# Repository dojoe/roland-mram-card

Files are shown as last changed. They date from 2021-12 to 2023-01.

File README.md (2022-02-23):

# Roland compatible multi-bank MRAM memory card

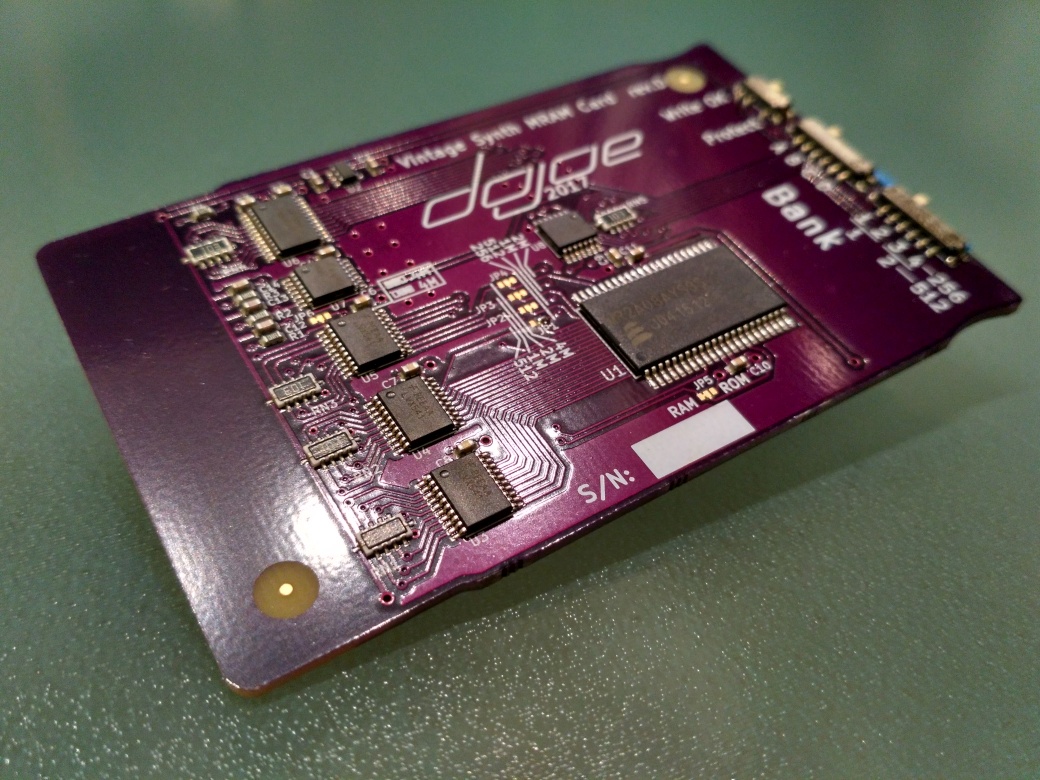
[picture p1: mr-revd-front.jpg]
[](mr-revd-front.jpg) (click to enlarge)

This is a replacement memory card for old Roland instruments of the late 80s and early 90s, such as the D-50 synthesizers, the JV-1080 and JV-2080 rack synths or the JD-880. It is meant to replace memory cards of the M-128, M-256 and M-512 lines (including M-256E, M-512G and all other suffixes). Some Akai devices from the same age actually use a compatible card format (BR-16 and BR-32) and this card will work in those too.

It doesn't need any kind of backup battery since it uses non-volatile MRAM for data storage, and thanks to the large memory chip used it emulates multiple virtual cards ("banks") which are selectable via slide switches - one of these memory cards will emulate 8x M-512 or 16x M-256 depending on the setting of a solder jumper.

The card has been developed with a lot of testing help from the community over at [the VintageSynth forums](https://forum.vintagesynth.com/viewtopic.php?f=24&t=76886) and over 900 units have been manufactured and sold since then - with near zero complaints :) Since the beginning of the project, we had plans to eventually publish the design data and source code for the card so it would stay available to everyone once we stopped making and selling them. So here it is!

## Compatibility

* **Tested and fully compatible:** Roland A-90, D-5, D-20, D-50, D-550, D-10, D-110, D-70, U-20, JD-800, JD-990, JV-880, JV-1000, JV-1080, JV-2080, R-880 (GC-8), R-8M, GR-1, GR-50, PM-16, TR-626, Akai MX-1000, VX600.
* **Mostly compatible:** Roland TD-10, TD-20. The card reportedly has errors when inserted all the way, but pulled back 1/8th of an inch it works fine.
* **Not compatible:** Roland VG-8, Peavey Tubefex.
* Some units like the Roland U-110 and U-220 only accept ROM cards, not RAM cards. Naturally, this RAM card replacement does not work in those, either.

## Differences to the cards we sell

Functionally, this design is 100% identical to the cards we sell online. I did make some changes to the appearance however to make homemade cards clearly distinguishable from ours.

Also, one part we use (a Bourns CAT25 SMD resistor network) is no longer being manufactured, so I updated the BOM with a Panasonic part as a drop-in replacement.

## Directories

* [mram-card](mram-card): The memory card hardware design files.
* [datasheets](datasheets): Data sheets for most of the parts used.
* [testbench](testbench): The testbench I'm using to test every card before they go out to customers.

## Making cards

Send the [KiCAD PCB file](mram-card/d50mram.kicad_pcb) or the [Gerbers](mram-card/gerbers.zip) to your favorite board house - or order directly from OSHPark:



As for parts, check out the [bill of materials](mram-card/d50mram.bom.csv).

Did you build one, or even more than one? We'd love to hear from you, feel free to leave a comment in the [card builder thread](https://github.com/dojoe/roland-mram-card/issues/2) :)

# Licenses

## Memory card

<br /><span xmlns:dct="http://purl.org/dc/terms/" property="dct:title">The hardware design of the <a href="https://github.com/dojoe/roland-mram-card">Roland compatible multi-bank MRAM memory card</a></span> by <a xmlns:cc="http://creativecommons.org/ns#" href="https://github.com/dojoe" property="cc:attributionName" rel="cc:attributionURL">Joachim "dojoe" Fenkes</a> is licensed under a <a rel="license" href="http://creativecommons.org/licenses/by-sa/4.0/">Creative Commons Attribution-ShareAlike 4.0 International License</a>.

## Testbench

Please see the [testbench README](testbench/README.md) for testbench license information.

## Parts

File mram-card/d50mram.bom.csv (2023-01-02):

Source: | D:\Projects\d50_mram_card\opensource\mram-card\d50mram.kicad_sch
Date: | 2023-01-02 14:01:17
Tool: | Eeschema (6.0.7)
Generator: | C:\Program Files\KiCad\6.0\bin\scripting\plugins/bom_csv_grouped_by_value.py
Component Count: | 42
Individual Components:
Item | Qty | Reference(s) | Value | LibPart | Footprint | Datasheet | Digikey | Mouser
 |  | C1 | 1uF X7R | d50mram:C
 |  | C2 | 1uF X7R | d50mram:C
 |  | C3 | 100n | d50mram:C
 |  | C4 | 100n | d50mram:C
 |  | C5 | 100n | d50mram:C
 |  | C6 | 100n | d50mram:C
 |  | C7 | 100n | d50mram:C
 |  | C8 | 100n | d50mram:C
 |  | C9 | 100n | d50mram:C
 |  | C10 | 100n | d50mram:C
 |  | C11 | 100n | d50mram:C
 |  | C12 | 100p | d50mram:C
 |  | C13 | 100p | d50mram:C
 |  | C14 | 100p | d50mram:C
 |  | J1 | D50-EDGECONN | d50mram:D50-EDGECONN
 |  | JP1 | JUMPER3 | d50mram:JUMPER3
 |  | JP2 | JUMPER3 | d50mram:JUMPER3
 |  | JP3 | JUMPER3 | d50mram:JUMPER3
 |  | JP4 | JUMPER3 | d50mram:JUMPER3
 |  | JP5 | JUMPER3 | d50mram:JUMPER3
 |  | JP6 | JUMPER3 | d50mram:JUMPER3
 |  | R1 | 100R | d50mram:R
 |  | R2 | 100R | d50mram:R
 |  | R3 | 100R | d50mram:R
 |  | R4 | 100R | d50mram:R
 |  | RN1 | 10k | d50mram:CAT25 |  |  | U8103CT-ND | 667-EXB-E10C103J
 |  | RN2 | 10k | d50mram:CAT25 |  |  | U8103CT-ND | 667-EXB-E10C103J
 |  | RN3 | 10k | d50mram:CAT25 |  |  | U8103CT-ND | 667-EXB-E10C103J
 |  | RN4 | 10k | d50mram:CAT25 |  |  | U8103CT-ND | 667-EXB-E10C103J
 |  | RN5 | 10k | d50mram:CAT25 |  |  | U8103CT-ND | 667-EXB-E10C103J
 |  | SW1 | SPDT | d50mram:SPDT |  |  | 563-1102-1-ND | 229-CUS-12TB
 |  | SW2 | SP4T | d50mram:SP4T |  |  | 563-1104-1-ND | 229-CUS-14TB
 |  | SW3 | SP4T | d50mram:SP4T |  |  | 563-1104-1-ND | 229-CUS-14TB
 |  | TP1 | CONN_6 | d50mram:CONN_6
 |  | U1 | EST-MR2A08A | d50mram:EST-MR2A08A |  |  | 819-1004-ND | 936-MR2A08AYS35
 |  | U2 | MIC5265-3.3YD5 | d50mram:TC1054 |  |  | 576-2835-1-ND | 998-MIC5265-3.3YD5TR
 |  | U3 | 74LVX541 | d50mram:74LS541 |  |  | 74LVX541MTCXCT-ND | 512-74LVX541MTCX
 |  | U4 | 74LVX541 | d50mram:74LS541 |  |  | 74LVX541MTCXCT-ND | 512-74LVX541MTCX
 |  | U5 | 74LVX541 | d50mram:74LS541 |  |  | 74LVX541MTCXCT-ND | 512-74LVX541MTCX
 |  | U6 | 74LVX4245 | d50mram:74x4245 |  |  | 74LVX4245MTCXCT-ND | 512-74LVX4245MTCX
 |  | U7 | 74HC02 | d50mram:74LS02P |  |  | MM74HC02MTCXCT-ND | 512-MM74HC02MTCX
 |  | U8 | 74HC02 | d50mram:74LS02P |  |  | MM74HC02MTCXCT-ND | 512-MM74HC02MTCX
Collated Components:
Item | Qty | Reference(s) | Value | LibPart | Footprint | Datasheet | Digikey | Mouser
1 | 2 | C1, C2 | 1uF X7R | d50mram:C
2 | 9 | C3, C4, C5, C6, C7, C8, C9, C10, C11 | 100n | d50mram:C
3 | 3 | C12, C13, C14 | 100p | d50mram:C
4 | 1 | J1 | D50-EDGECONN | d50mram:D50-EDGECONN
5 | 6 | JP1, JP2, JP3, JP4, JP5, JP6 | JUMPER3 | d50mram:JUMPER3
6 | 4 | R1, R2, R3, R4 | 100R | d50mram:R
7 | 5 | RN1, RN2, RN3, RN4, RN5 | 10k | d50mram:CAT25 |  |  | U8103CT-ND | 667-EXB-E10C103J
8 | 1 | SW1 | SPDT | d50mram:SPDT |  |  | 563-1102-1-ND | 229-CUS-12TB
9 | 2 | SW2, SW3 | SP4T | d50mram:SP4T |  |  | 563-1104-1-ND | 229-CUS-14TB
10 | 1 | TP1 | CONN_6 | d50mram:CONN_6
11 | 1 | U1 | EST-MR2A08A | d50mram:EST-MR2A08A |  |  | 819-1004-ND | 936-MR2A08AYS35
12 | 1 | U2 | MIC5265-3.3YD5 | d50mram:TC1054 |  |  | 576-2835-1-ND | 998-MIC5265-3.3YD5TR
13 | 3 | U3, U4, U5 | 74LVX541 | d50mram:74LS541 |  |  | 74LVX541MTCXCT-ND | 512-74LVX541MTCX
14 | 1 | U6 | 74LVX4245 | d50mram:74x4245 |  |  | 74LVX4245MTCXCT-ND | 512-74LVX4245MTCX
15 | 2 | U7, U8 | 74HC02 | d50mram:74LS02P |  |  | MM74HC02MTCXCT-ND | 512-MM74HC02MTCX

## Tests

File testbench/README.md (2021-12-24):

# Roland Memory Card Testbench

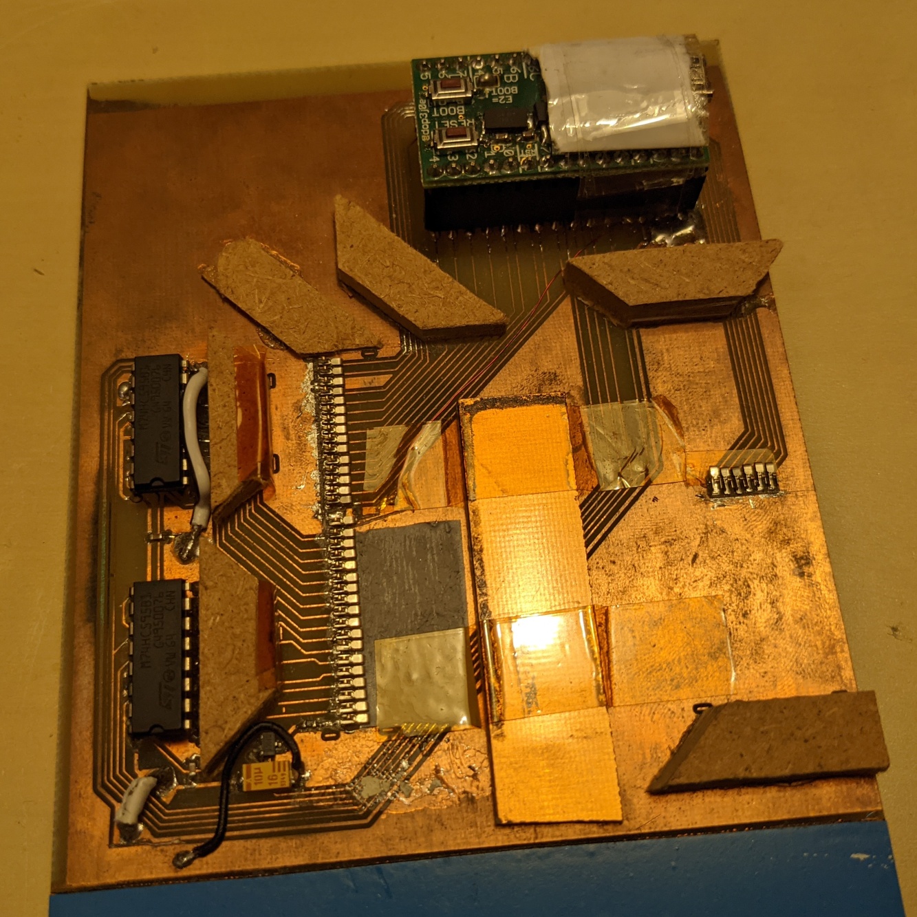
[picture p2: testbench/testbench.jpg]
[](testbench.jpg) (click to enlarge)

This is a quick and dirty test jig I built to test the memory card. It performs these tests, in order:

1. Check voltage rails (5V provided from outside, 3.3V generated on the card).
2. Single bank full read/write with data checking to test address and data lines.
3. Test write protect and bank switches - the user is prompted to operate the switches while the test program monitors the switch positions.
4. Verify bank switching logic - while the bank switches are tested, the test program writes a byte value identifying the bank to each and checks in a second pass that all values are read back correctly.

In addition to that it also has a couple debugging features: It can write and read memory cards (one bank at a time) and dump the current value of all microcontroller IO ports to the serial console (to test the test jig itself).

# Hardware

The test jig is built around my ATMega32U4 mini breakout board, the TinyMega - any 32U4 based Arduino board should do the trick though. I updated the schematics to reflect a more generic ATMega32U4 and added the user LED and user button that are connected to pins E6 and E2 on my board respectively.

**The PCB layout is only for illustrative purposes and not recommended for use!** It no longer matches the schematics, does not reflect some board modifications I have made in the meantime, and generally is a quick single-sided abomination I whacked together to get a test jig made over the weekend :) You can copy the arrangement of the spring contacts but should really redesign the rest from scratch.

Speaking of which, the spring contacts I've used are ["Micro Universal Contact Z 2.5mm"](../datasheets/springcontact.pdf) by ITT Cannon, Digikey P/N 120220-0312.

As you can see when looking at the schematics, the test jig uses every single I/O pin of the microcontroller. Address bits A0..A15 are generated via a chain of 74HC595 shift registers, all other signals are operated and monitored directly. Pin E6 ends up doing double duty - usually it just drives the LED to indicate test progress but a special 1Mbit write/dump mode was added later on that uses this pin for an additional address line.

A P-MOSFET is used to turn power to the card under test on and off; the small series resistor R2 limits the current in case of a short or near-short on the card. It will also cause a significant voltage drop in case the card isn't shorted but draws more current than expected - this will be detected in step 1 above and will fail the test.

The memory card has six test points that are used to read back the position of the four-way slide switches. The test program will poll these (with some debouncing logic) to pace the progress of steps 3+4 above in lockstep with the user moving the switches.

# Software

The test program is as quick and dirty a hack as is the hardware - it is based on the VirtualSerial demo program from the LUFA USB library, with almost no modifications to the USB serial code. All the test code is contained within [test.c](firmware/test.c), which is the only file _not_ shamelessly yoinked from LUFA.

The test program has four modes:

* Test mode, which will execute the test sequence.
* Dump mode, which will dump the entire card content to the serial console as a binary stream.
* Program mode, which will write binary data coming in via the serial console to the card.
* DIO monitor mode, which will keep printing the state of the I/O ports to the serial console.

For Test, Dump and Program mode, you can additionally select a card size; Test mode supports 256 and 512 kbit, Dump and Program modes additionally support 128 and 1024 kbit cards. The default upon startup is Test mode for 256 kbit cards.

You can switch modes by sending characters over the serial link: t, p, d, m select Test, Program, Dump and Monitor mode respectively, and 1..4 select 128, 256, 512 and 1024 kbit sizes.

To connect to the test jig, use a simple terminal program like [RealTerm](https://realterm.sourceforge.io/).

Regardless of mode, pushing the user button starts an operation.

## Test mode

Once you push the button, the test program will run through the tests in this order:

1. Turn off the user LED (in case it was turned on)
2. Test voltage rails
3. Check that all slide switches are in the right position (write protect off, bank A1 selected)
4. Read/write test of bank A1
5. Detect card size, fail if detected size doesn't match what's configured via serial
6. Turn on the user LED to indicate progress to the user
7. Test write protect switch: User must turn write protect on, then off again
8. Turn the user LED back off
9. Test ABCD bank switch: User must move switch through all positions from A thru D and then back again
10. Test 1234 bank switch in the same way
11. If we get here without error, the test passes - turn on the user LED to indicate success

If any of these steps fails, the test will abort and the user LED will blink. Also, whenever the program is waiting for user action, the user can instead push the button to abort the test.

## Dump mode

Once you push the button, the test program will read the entire card and output the contents to the serial link as a stream of bytes. The idea is that you configure dump mode and the correct size via your terminal program, then start a capture to file in the terminal program and push the button.

## Program mode

This is similar to Dump mode, except that your terminal program will be the one sending bytes to the test jig. As you push the button, the test program will print a message prompting you to send data, then you can have your terminal program send a binary file directly to the serial line. The test program will expect exactly as many bytes as you set up earlier.

# Licenses

 <p xmlns:cc="http://creativecommons.org/ns#" xmlns:dct="http://purl.org/dc/terms/">The hardware (schematics, example layout) of <a property="dct:title" rel="cc:attributionURL" href="https://github.com/dojoe/roland-mram-card/tree/master/testbench">Roland Memory Card Testbench</a> by <a rel="cc:attributionURL dct:creator" property="cc:attributionName" href="https://github.com/dojoe">Joachim "dojoe" Fenkes</a> is marked with <a href="http://creativecommons.org/publicdomain/zero/1.0?ref=chooser-v1" target="_blank" rel="license noopener noreferrer" style="display:inline-block;">CC0 1.0</a></p>

The actual test code, [test.c](firmware/test.c), is licensed under [the Unlicense](https://unlicense.org).

All other code in the firmware directory is copied or adapted from [LUFA](http://www.fourwalledcubicle.com/LUFA.php) and covered by [LUFA's license](firmware/LUFA/License.txt).

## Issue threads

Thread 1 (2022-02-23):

Equivalent Drop-In SMD Resistor Network

MrMojoRisinGottaKeepOnRisin, 2022-02-23:
I just built and tested three DOJOE Roland MRAM Cards using the new part from Panasonic (P/N: **EXB-E10C103J**) and all is well. The equivalent SMD Resistor Network you have listed in the BOM is indeed a valid drop-in replacement for the Bourns CAT25. Same footprint, specs and everything.

dojoe, 2022-02-23:
Thanks a lot for reporting back! I updated the README.

Closed 2022-02-23.

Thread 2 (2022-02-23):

Card builder thread!

dojoe, 2022-02-23:
Built your own card(s)? Leave a comment in here so we know how far our design is spreading :) We'd be interested in your rough location too (out of pure curiosity) but we'll also be happy if you just say hi!

MrMojoRisinGottaKeepOnRisin, 2022-02-23:
I'm on the East Coast, U.S.A. I purchased a pre-built Roland Multi-Bank MRAM Card back in 2021. One of the coolest new gadgets I own! I'm very grateful to the designer for the newly released BOM, schematics and plans. I commend DOJOE for supplying all of this free info and for supporting the DIY community. Very generous, indeed!! I have built three of these new cards from scratch so far and they all work great. Assembly was easy and the components are spaced out on the PCB with minimal crowding. I was able to solder all components by hand and did not use solder paste or a solder plate. Lots of flux. I used OSHPark to fabricate the PCB's and have always had outstanding luck with that company over the years. Quick turnaround and **Free Shipping** to anywhere in the world!

maddmannmatt, 2022-03-21:
Forgive my confusion on this matter, but does OSHPark build the whole card for you or do they just provide the PCBs?

MrMojoRisinGottaKeepOnRisin, 2022-03-21:
_> Forgive my confusion on this matter, but does OSHPark build the whole card for you or do they just provide the PCBs?_

OSHPark only supplies the PCB's. You need to source all of the parts and solder all of the components yourself.

andyc2k, 2022-04-06:
Thanks for open-sourcing this! FYI, it looks like the Panasonic EXB-E10C103J resistor network is out of stock on both DigiKey & Mouser, but there are still some Bourns CAT25-103JALF available from RS.

Benito-H, 2022-07-13:
I'm from Vancouver BC, and will be building one of these for my D-110. I have all the data sheets, but have a question about the surface mount capacitors and resistors.  What rating should I get (operating voltage/power rating), as there is a wide range to choose from, and this info is not included in the data sheets?  I am a newbie at this so apologize for my ignorance.

MrMojoRisinGottaKeepOnRisin, 2022-07-14:
> The board (sent Gerbers to PCBWAY) with all components installed is an extremely tight to fit into the card slot. The main RAM chip actually has a line/mark down it from being inserted into the card slot. What thickness were the original production boards?

I measured my original production PCB and it is 1.5mm. The DIY PCB's I bought from OSHPark are 1.4mm. I don't get any lines/marks when using either on a U-20, D-110 or JV-880 and both versions are a good fit on these three synths when inserting/removing.

MrMojoRisinGottaKeepOnRisin, 2022-07-14:
> I have all the data sheets, but have a question about the surface mount capacitors and resistors. What rating should I get (operating voltage/power rating)?

For my DIY synth projects using SMD components, when choosing resistors and capacitors without any specs shown in the BOM (just to play it safe) I always use Resistors 100V or greater @1/4W and Capacitors 35V or greater. Prior to the component shortage and price hikes of 2020, the extra cost for this high Voltage ceiling was minimal. Nowadays, urrrghhhhh!

These are the resistors and capacitors I used for my build:
100 Ohm - PANASONIC P/N: **ERJ-PA3F1000V**
10K Array - PANASONIC P/N: **EXB-E10C103J**
100pF - MURATA P/N: **GCM1885C2A101FA16D**
100nF - TDK P/N: **C1608X7S2A104K080AB**
1uF - TDK P/N: **CGA3E1X7R1V105K080AE**

Benito-H, 2022-07-16:
Hi MrMojo,

Great. thank you for your help. I am ordering the components from mouser, but there is a back order on the MIC5265-3.3YD5 chip until October.  I'll have to be patient, I guess.  Grrrr!

andyc2k, 2022-07-18:
I've built a couple of cards here in Tokyo using PCBs from OSHPark. I'm planning to use this to make a permanent backup of the Akai VX600 factory presets and ideally dump the data to a file. Next step will be to build the test jig - has anyone else tried this yet?

dojoe, 2022-07-18:
> The board (sent Gerbers to PCBWAY) with all components installed is an extremely tight to fit into the card slot. The main RAM chip actually has a line/mark down it from being inserted into the card slot. What thickness were the original production boards?

@MartyMidi The original boards were 1.6mm plus parts. Some devices' slots have a habit to warp and become tighter with age; that's when they scrape the main memory chip. This is known to happen in JD-1080s for example and isn't causing any kind of problem.

> What rating should I get (operating voltage/power rating), as there is a wide range to choose from, and this info is not included in the data sheets?

@Benito-H For caps, the board runs at 3.3V or 5V; I usually pick twice that for margin, so 10V should be plenty. As for stability rating, go with X7R; at the capacitances the board uses the X7Rs aren't more expensive than the lesser ratings these days.

For the resistors, use the ubiquitous 1/10W type, that's the cheap jellybean type for 0603 sizes and none of these will be seeing any significant current.

> Next step will be to build the test jig - has anyone else tried this yet?

@andyc2k Not that I'm aware of; you'll probably have to redesign most of the board (I take it you already saw the big fat warning in the README) and add the actual ATmega part plus support components instead of the devboard header I had on there. If you do I would be delighted about a PR :)

> I am ordering the components from mouser, but there is a back order on the MIC5265-3.3YD5 chip until October.

@Benito-H You may want to check out #5 :)

Benito-H, 2022-07-19:
@dojoe Thanks for the pointer to #5 I have ordered the alternate part, and all the other components.

tsanderakis, 2022-07-28:
Cant`t get my card running. It`s for a Roland D550 but it is allways telling me  "illegal card" Can`t find really good information on how formatting cards with my D550. Think this is a different procedure like the Keyboard D50 version. The solder on the card is on the right side for 256 at JP1. PCB is from JLCPCB and 1.6mm. I was thinking that 0.1mm more is not that much and in my opinion and feeling when pushing it in it fits well.
https://www.sweetwater.com/sweetcare/articles/roland-d-550-saving-ram-card/
Arrays are again avaiable at Mouser.

dojoe, 2022-07-28:
There must be an "initialize" option in some tools menu. That's what formatting is called on some Rolands. Illegal card usually just means it needs to be initialized. Remember that you have to initialize each bank separately. (Also remember to read the manual if you haven't already.)

If after initialization the card is still "illegal" there might be something bad about the hardware (like a badly connected address or data line).

tsanderakis, 2022-07-28:
The dokumentation of the D550 seems a little bit confusing. In the service manual, found one on the net, they are writing for testmode press and hold patch bank 2, patch bank 6, and edit and turn machine on. Looks like there is a translation error in the manual. If you use exit instead of edit its working.

Einschalten, während Sie die folgenden Tasten gedrückt halten:

1> PB2+PN6+edit=ROM-Versionsnummer identifizieren
2> PB2+PN6+exit=Testmodus aufrufen
3> PB2+PN6+enter=Initialisierung (Werkseinstellung wiederherstellen)
4> PB2+PN6+write=D/A-Anpassungsmodus aufrufen
found this on the net.

In test mode the card shows no read no write so no wonder not initialized but finds something. So what I try tomorrow is building a second card.  I have 2xD550 and on both same problems. Found in the original owners manual just only somewhere press 2x enter when it is not possible to write to the card. ???
Soldering? Not a total beginner. Did some STMs in the last few years and 0603.
Nothing like for D50 keyboard version.
Data Transfer, Int->Crd, Split-Point press and hold, press Enter

sorry, rough location is Upper Neanderthal

tsanderakis, 2022-07-29:
Ready with No. 2. This one is working so everything fine. For initializing you have just to press Data Transfer,  with cursor button go to int->card, press enter button, when you see illegal Card push enter again and then once more enter. This is for D550 not for D50. So now I have to find out whats wrong with No. 1.
@dojoe  Thanks for your help

andyc2k, 2022-08-21:
Hi. I was able to build the test jig and dump the binary data from my VX600. I used a standard Arduino Micro and a custom card-to-pin header adapter to connect it to a breadboard. The test however fails at "Reading first 32K again" at a seemingly random (high offset) address, which seems to change if I uncomment the delays in test.c. I'll look into it some other time - it seems to work fine regardless.

Notes:
- PD5 (data bit 6) is used for the TX LED on the Arduino Micro. I held a jump wire against a nearby via as a workaround.
- There's no PE2 pin on the Arduino Micro. I added an 'S' command for start/stop instead.
- I used the same spring contacts and held the card down with my hand, but there has to be a better way. The orientation of the pins is important because they're designed to be forced downward in the direction of insertion.

DocRV, 2022-10-19:
Hallo DoJoe,
I'm located near Paris. I've created this account just to thank you. I bought you a card, long ago and now I built few cards by my own (6 so far). I sold some of them. I saw your comments on VintageSynth forums and I stick to a fair price. It is incredibly generous from you to share your work. I really admire your schematic design, even if I complain so many times you've used 0603 CMS components. My old eyes hate you ! ;-). You're great ! Vielen Dank ! Tschüss,

dojoe, 2022-10-19:
> The test however fails at "Reading first 32K again" at a seemingly random (high offset) address, which seems to change if I uncomment the delays in test.c. I'll look into it some other time - it seems to work fine regardless.

There's a 99.9% chance it's the spring contacts. Don't ask me how many mods I had to make to the test jig until those contacts worked even semi reliably. In the testbench photo you'll notice a slab of bare PCB taped to the jig surface. That's to make sure the memory card doesn't bottom out on the spring contacts; if it does the contacts' casings will randomly contact the next pin over. Took me a while to figure out.

guytaylor, 2023-05-10:
Hi everyone!
I've made a few of these cards, and they are working fine. But I do get a bit worried about them being fragile and potentially knocking components off.
Has anyone tried sealing it with some kind of protective coating? or something like that?

guytaylor, 2023-05-13:
Also, the 74LVX4245MTCX are not available from the usual big suppliers anymore.
But are available here (albeit with very high shipping :( )
https://www.utmel.com/productdetail/onsemiconductor-74lvx4245mtcx-7586388

Hydrot, 2023-10-10:
Hello, I've been following your old blog to get to here. I'm building the card now. I'm wonder if anyone has a picture of when inserted the card on Roland D-50 how much of the card goes inside. I'm planning to build a case for it and include some holes on the PCB. I also would like to congratulate Dojoe for this fantastic work he spent all time to get to here. This is some serious Engineering. I belong a to a huge community on facebook and there's a lot of people interested on this. I'm PCB Designer and Engineer as well. I also want to get your blessing to sell the board with some modifications. Please let me know! I'm not trying to copy your design and make money but help the great community of D-50. So, my plan is to run some lot of boards with my changes. I own a D-50 and a Juno DS.

sagamusix, 2023-10-17:
@Hydrot the final card has pretty much the same dimensions in terms of width and height as an original RAM/ROM card, so you can use those for reference, but here's a picture of the card in my D-50:

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

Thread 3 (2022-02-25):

Quirks For Roland U-20 Owners (And Possibly Other Synths)

MrMojoRisinGottaKeepOnRisin, 2022-02-25:
#1) When using this with the Roland U-20 and inserting a freshly built card for the first time, the error message _**"**RAM Card Verify Error!**"**_ appears and continuing on to format the card is not possible. This is solved by removing the card and changing both BANK switches to the far right to select the very last bank (D-4). After doing that and re-inserting the card, the desired message appears and says, _**"**It's a New RAM Card. Initialize it? [ ENTER ]**"**_. All other banks are able to properly initialize from that point on

Another quirk about the U-20 is that it will show an informational message every time the card is inserted and a properly formatted bank is selected. It says, _**"**RAM Card Battery Low!**"**_. However, this is expected behavior because there is no battery on the new MRAM card. This is just a leftover from the old technology and it does not affect operation of the new MRAM card in any way

sagamusix, 2022-03-05:
1) Seems strange - from the synths' perspective, all 16 cards should be filled with garbage when inserted for the first time, and the synth cannot tell those 16 cards apart (i.e. there is no reason why D4 should work while A1 shouldn't). The error message you got initially could hint at the card not being inserted properly, and using the bank select switches might have moved the card in the slot just enough that the synth could read it properly again. I also have this with my D-50 sometimes, and just moving the card around a bit in the slot solves the issue (but in my case I suspect the problem is due to the slot being a bit damaged from very early memory card experiments, so most other owners shouldn't see this issue with the D-50).

Regarding point 2), just to avoid confusion - our card *does* report a battery voltage to the synth. So the behaviour is not exactly "expected". However, the voltage is 3.3V (like what's expected by the memory chip) rather than the typical 3V provided by a coin cell battery at most. We suspect that some synths cannot handle this extra 0.3V in their calculations of the battery state and end up with a wrong result and thus showing a warning. As far as we're aware, only the U-20, JV-1080 and JV-2080 have this problem, and it's mentioned in the FAQ section of the manual.

MrMojoRisinGottaKeepOnRisin, 2022-03-21:
Thanks for clearing this up. Your explanation about Point #1 makes perfect sense so... not an issue. re: Point #2, Ooops! I overlooked that part in the manual.

sagamusix, 2023-12-06:
I got my hands on a U-20 temporarily and interestingly, I don't see the second issue here, i.e. no "low battery" warning. Maybe it depends on the manufacturing date or firmware version whether this problem is exposed.
Can you confirm the OS version of your U-20? To do so, press PART and RHYTHM simultaneously to enter demo mode, then press MARK, JUMP and ENTER simultaneously to enter test mode. You should now see the OS version. Mine is V2.00 (89/06/16 1323).
According to the [serial number](https://serial-number-decoder.com/roland/roland.htm), it was manufactured in November 1989.

MrMojoRisinGottaKeepOnRisin, 2023-12-06:
_> Can you confirm the OS version of your U-20?_

I tried it again today and when I insert the card I no longer get a **_"RAM Card Battery Low!"_** message. The only thing different I can think of is that before, only three banks contained actual U-20 Patch data. The remaining 13 banks were only initialzed and formatted _(for use with the U-20)_. Today, all 16 banks are initialzed, formatted and contain U-20 Patch data.

My U-20 is V3.03 (89/10/30 1400)
Manufactured September 1991

_Test Mode 4_
R/W:**OK**
RAM Card Bat:**3.3V**

sagamusix, 2023-12-06:
Very interesting! It should definitely not depend on how many banks are initialized - the synth only sees a single bank at a time, and its contents do not change anything about the reported voltage. The only reason I could imagine why you had the problem once but not now is a power supply issue or anything else causing a fluctuation in power delivery. So the mystery remains for now...

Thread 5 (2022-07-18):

Replacement for MIC5265-3.3YD5-TR

HSBallina, 2022-07-18:
Since the MIC5265-3.3YD5-TR seems to be out of stock in most places, would the [MIC5245-3.3YM5-TR](https://www.mouser.se/ProductDetail/?qs=U6T8BxXiZAXkopuvjIDr5w%3D%3D) be a suitable replacement?

dojoe, 2022-07-18:
Yes, looks like it would. The footprint and parameters match the application. The most critical thing is device height - during early design I switched to the Micrel part from a different part (don't remember which) because that other part was too high and the card would not fit in the slot :) The MIC5245 is 1.45mm max like the MIC5265 so that's not a problem.

HSBallina, 2022-07-18:
Awesome, thank you :)

Closed 2022-07-18.

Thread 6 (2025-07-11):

Questions around the test bench

guytaylor, 2025-07-11:
I am planning on making one of the test bench but have a few question:

* What is the part number for MOS_P?
* And just verifying the 2 100nF are the the 74HC595s and the 4.7uF (I assume an electrolytic would be ok?) should be near the MOS_P?
* In the cards schematic there are 2 halves, the 3.3V and 5V. The test point connections from the test are 5V but going to the 3.3V section of the board. Is that safe? Should I put a level converter 5V->3.3V there?

Thanks!

dojoe, 2025-07-17:
Hey! Thanks for your interest! :)

1. I honestly don't know, I literally used whatever PMOS I had on hand that could switch 1A (not that I'd ever need that much current).
2. Yes, the 100n are decoupling caps for the 595s and the 4.7u is a reservoir for supplying the DUT via the PMOS.
3. In the current state of the firmware the test pins are only used as inputs to observe the bank switches. I needed to test the switches themselves anyway so the testbench asks me to manipulate the switches by hand and synchronizes its test flow to the switch state.

If you plan to control the test points I agree that you would need some kind of level translation. Probably nothing fancy, just add a pull-up to 3.3V (can steal those from VBAT) and use an open-drain configuration (toggle the port between input and driving a 0, never drive a 1). The upside of that is that you can still drive _and_ observe.

Oh, and I just remembered something important I forgot to add to the schematic - I added a 3.9 Ohm series resistor between the PMOS and the DUT. The testbench firmware enables the PMOS and then checks voltages via the VBAT and CST pins. The small series resistor doesn't cause a problem as long as everything is fine with the card but if there's high-ish current somewhere the 5V rail level will drop quickly and can be detected by the testbench. I don't have the time to update the schematics at the moment but now you know :)

Have fun, and let me know how it works out for you. I want pictures when it's done! :)

guytaylor, 2025-08-15:
Layout done. I'm a stripboard fan, so doing it that way :)

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

guytaylor, 2025-08-16:
Hardware built and tested (not with the card yet though)

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

I went with a relay rather than fet, as that's what I had.

Can I clarify something when you said:

"If you plan to control the test points I agree that you would need some kind of level translation. Probably nothing fancy, just add a pull-up to 3.3V (can steal those from VBAT) and use an open-drain configuration (toggle the port between input and driving a 0, never drive a 1). The upside of that is that you can still drive and observe."

As I am using a teensy (again what I had!), it's already 3.3V so no level conversion needed (I needed to level convert the Data, WE, CE and OE line back to 5V)

Looking at the schematic of the cards, The 6 test points/switches have pull-down resistors, and the switches connect to 3.3V
So isn't what you're saying above the wrong way round?

If I set the port to OUTPUT, and send a 0, then wouldn't that be the same as what the pull-down resistor is doing? i.e. making it 0?
If I set the port to INPUT, then it's still at 0.

So thought it would be, always drive a 1 (i.e. set to OUTPUT and send 3.3V out), and set it to an INPUT for 0, as the pull-down resistor is already holding it at 0.

Or I may not be understanding something! Any advice welcome :)

guytaylor, 2025-08-20:
I changed the teensy to a 4.1 as my wiring on the 3.2 was a bit dodgy and shortened all the wires and neatened them up. All the errors have now disappeared, so all good now :)

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

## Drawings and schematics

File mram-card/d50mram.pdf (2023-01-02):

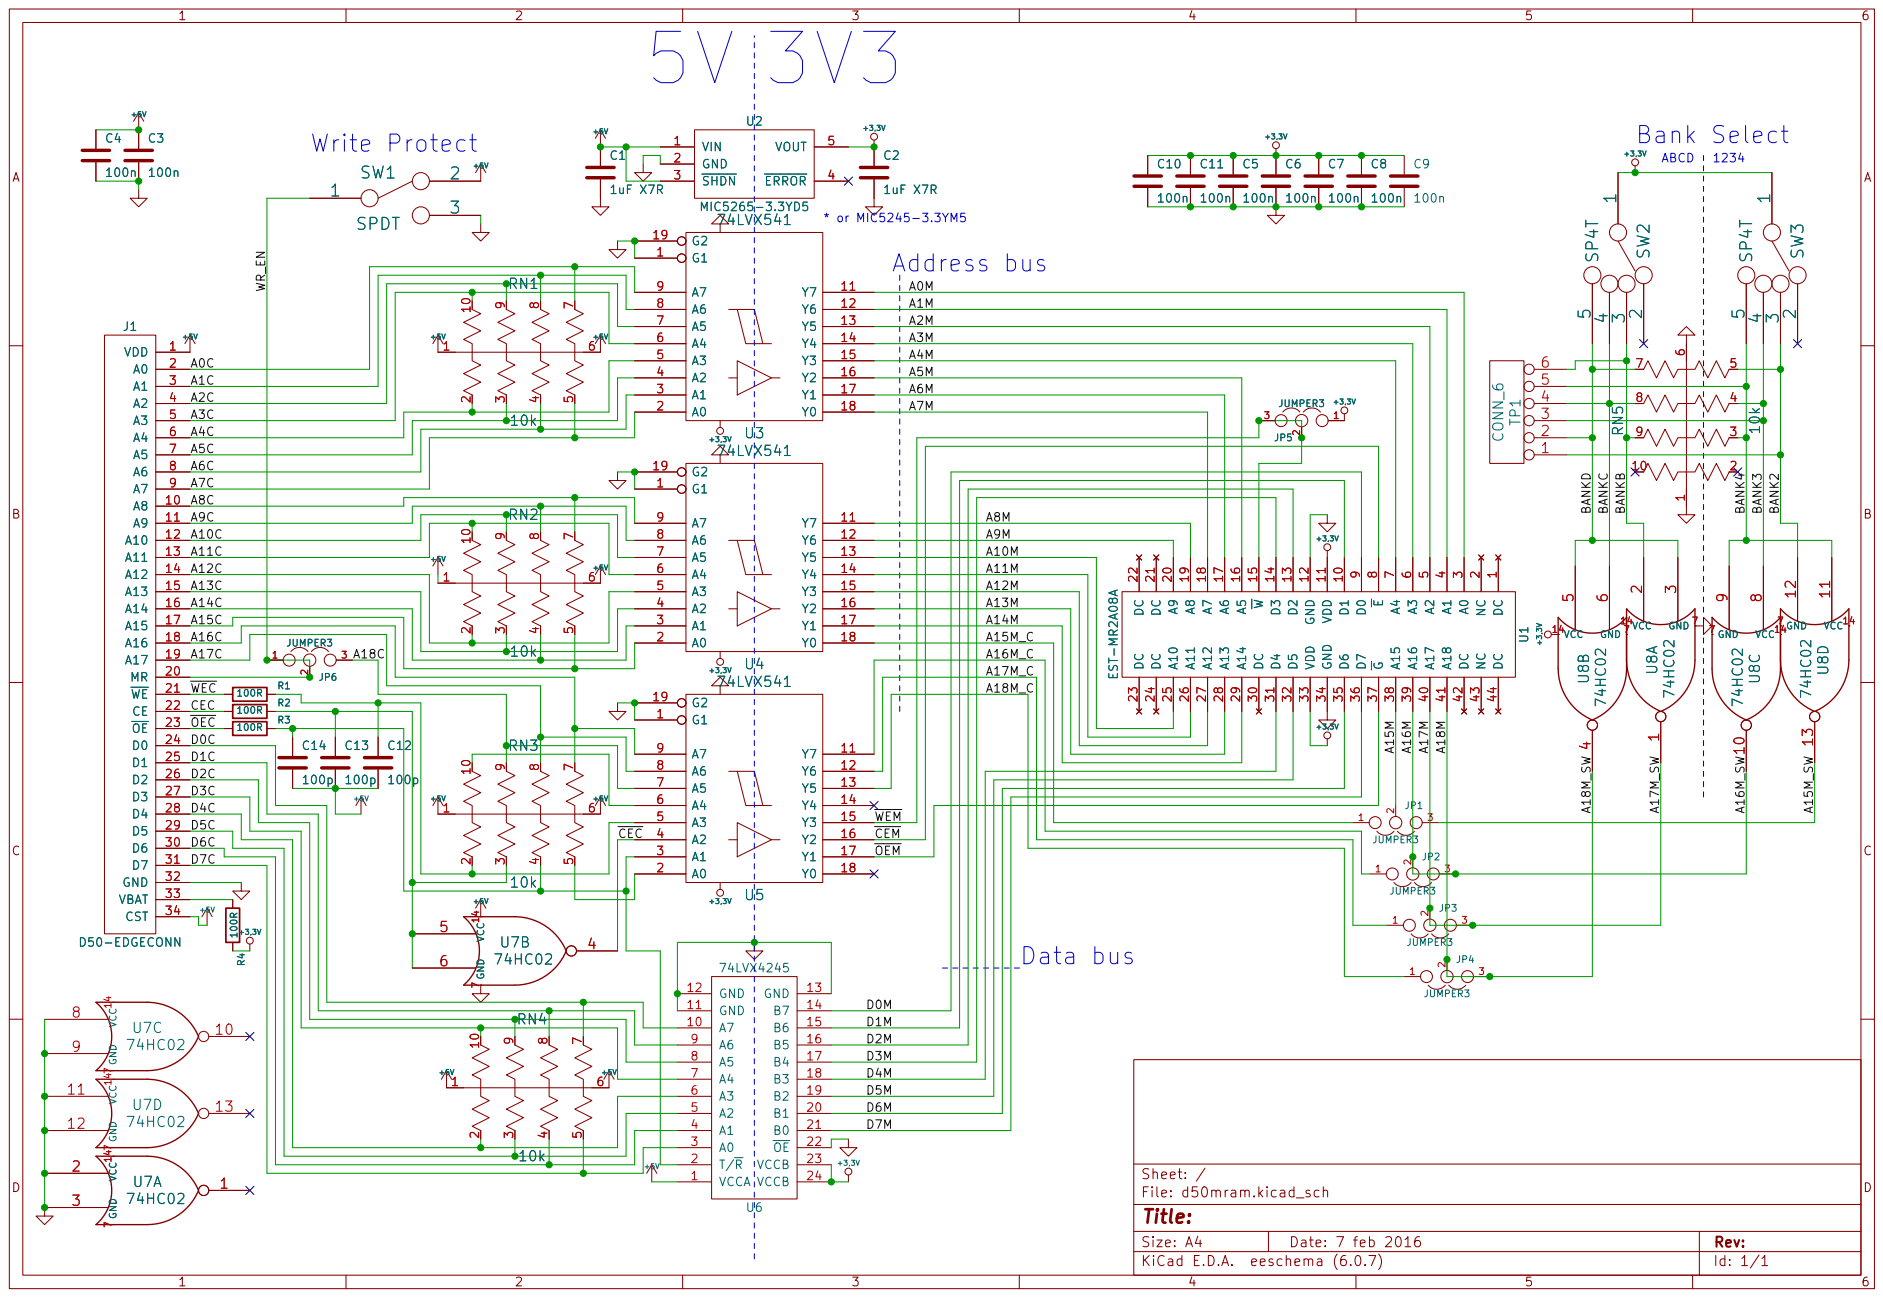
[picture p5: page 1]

7 U2 MIC5265-3.3YD5 VIN 1 GND 2 ~{SHDN} 3 ~{ERROR} 4 VOUT 5

A10C | A9M
A11C | A10M

A13C
A14C | A13M

JUMPER3 A18C 1 3

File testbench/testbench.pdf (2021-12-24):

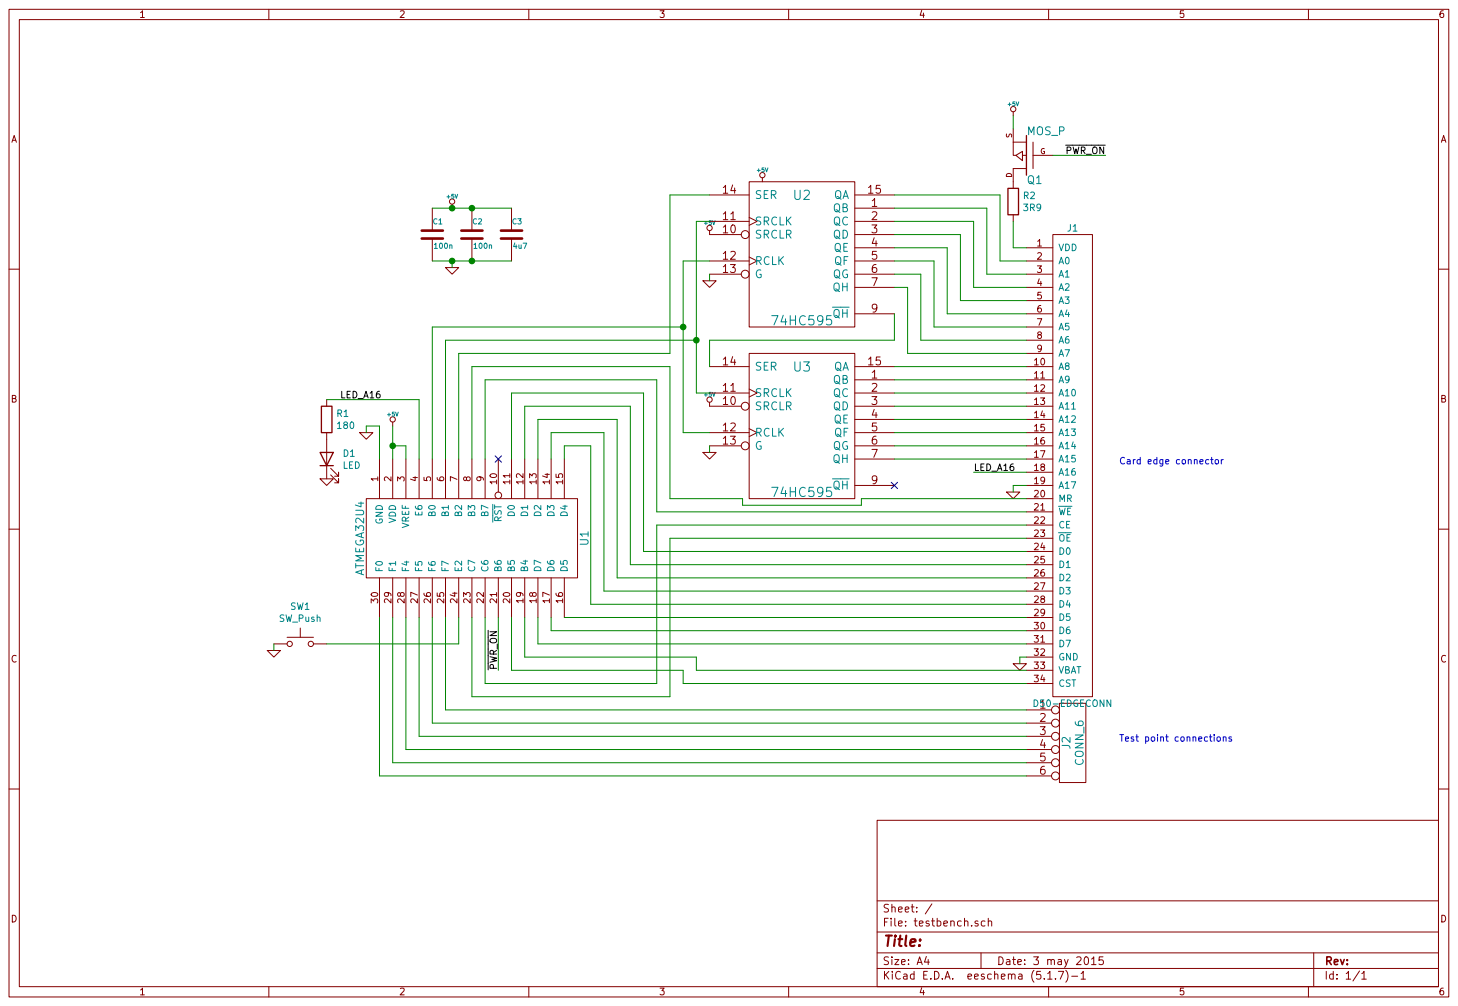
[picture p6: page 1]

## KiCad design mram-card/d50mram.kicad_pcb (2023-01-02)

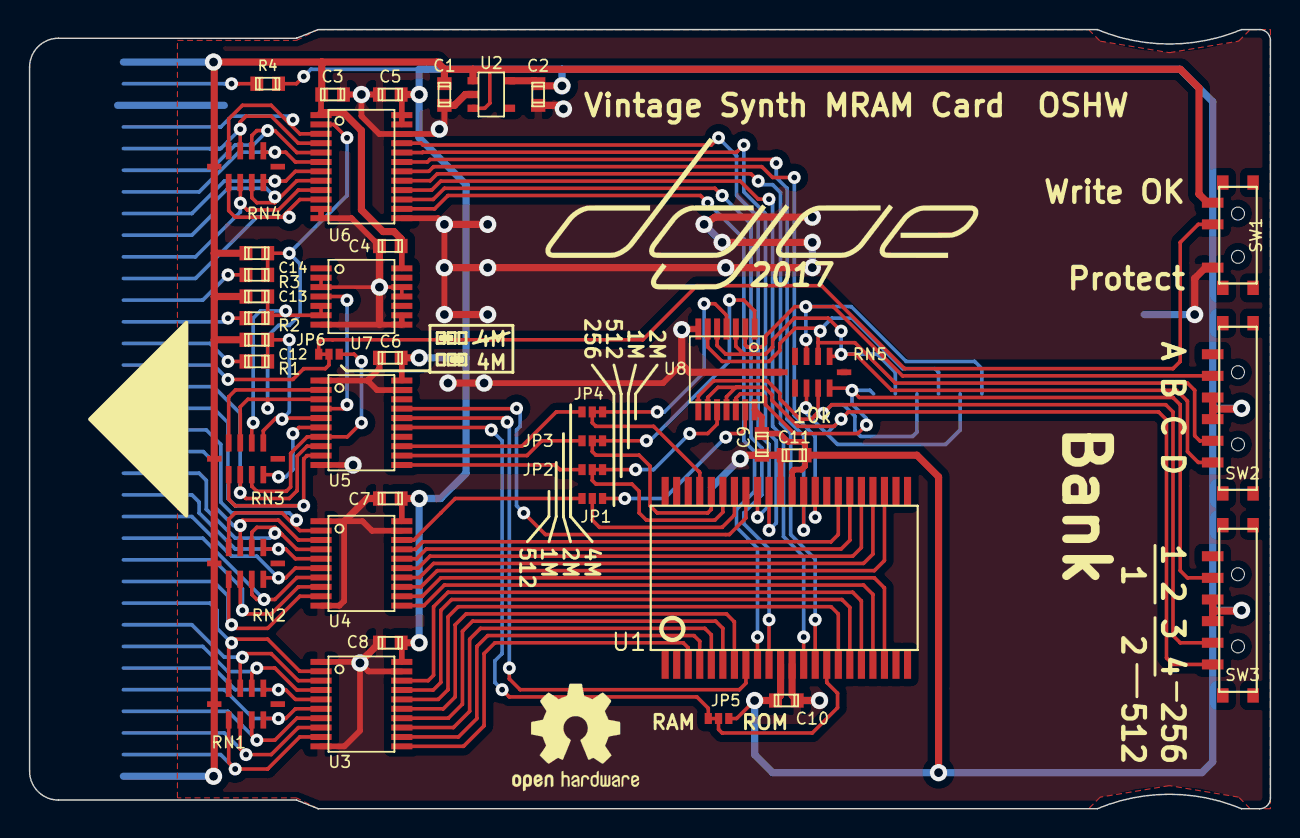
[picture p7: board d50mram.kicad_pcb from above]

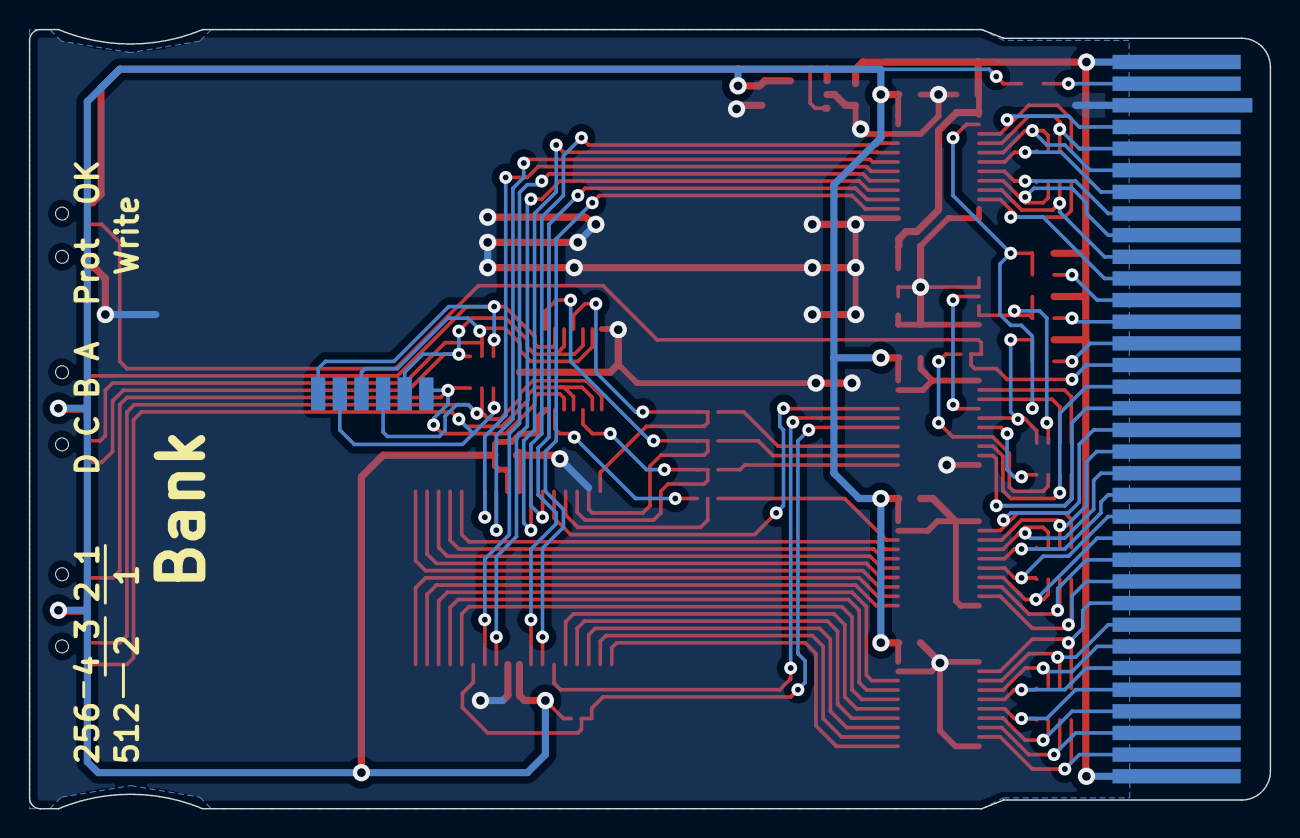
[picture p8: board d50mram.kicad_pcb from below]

Board: 2 copper layers, 86.0 x 54.0 mm, 43 parts (2 on the bottom side), 82 nets.

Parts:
C1, C2: 1uF X7R; c_0603
C3, C4, C5, C6, C7, C8, C9, C10, C11: 100n; c_0603
C12, C13, C14: 100p; c_0603
J1: D50-EDGECONN; EDGE1S34
JP1, JP2, JP3, JP4, JP5, JP6: JUMPER3; S_JUMPER_3
R1, R2, R3, R4: 100R; c_0603
RN1, RN2, RN3, RN4, RN5: 10k; CAT25
SW1: SPDT; CUS-12B
SW2, SW3: SP4T; CUS-14B
TP1: CONN_6; 6P_TESTPT
U1: EST-MR2A08A; TSOP2-44
U2: MIC5265-3.3YD5; SOT23-5
U3, U4, U5: 74LVX541; tssop-20
U6: 74LVX4245; tssop-24
U7, U8: 74HC02; tssop-14
VAL: REF; dojoe

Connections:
+3.3V: C2.1, C5.1, C6.1, C7.1, C8.1, C9.1, C10.1, C11.1, JP5.1, R4.2, SW2.1, SW3.1, U1.11, U1.33, U2.5, U3.20, U4.20, U5.20, U6.23, U6.24, U8.14
+5V: C1.1, C3.1, C4.1, C12.2, C13.2, C14.2, J1.1, J1.34, RN1.1, RN2.1, RN3.1, RN4.1, SW1.2, U2.1, U2.3, U6.1, U7.14
/A0C: J1.2, RN1.7, U3.9
/A0M: U1.3, U3.11
/A1C: J1.3, RN1.8, U3.8
/A1M: U1.4, U3.12
/A2C: J1.4, RN1.9, U3.7
/A2M: U1.5, U3.13
/A3C: J1.5, RN1.10, U3.6
/A3M: U1.6, U3.14
/A4C: J1.6, RN1.2, U3.5
/A4M: U1.7, U3.15
/A5C: J1.7, RN1.3, U3.4
/A5M: U1.16, U3.16
/A6C: J1.8, RN1.4, U3.3
/A6M: U1.17, U3.17
/A7C: J1.9, RN1.5, U3.2
/A7M: U1.18, U3.18
/A8C: J1.10, RN2.7, U4.9
/A8M: U1.19, U4.11
/A9C: J1.11, RN2.8, U4.8
/A9M: U1.20, U4.12
/A10C: J1.12, RN2.9, U4.7
/A10M: U1.25, U4.13
/A11C: J1.13, RN2.10, U4.6
/A11M: U1.26, U4.14
/A12C: J1.14, RN2.2, U4.5
/A12M: U1.27, U4.15
/A13C: J1.15, RN2.3, U4.4
/A13M: U1.28, U4.16
/A14C: J1.16, RN2.4, U4.3
/A14M: U1.29, U4.17
/A15C: J1.17, RN2.5, U4.2
/A15M: JP1.2, U1.38
/A15M_C: JP1.1, U4.18
/A15M_SW: JP1.3, U8.13
/A16C: J1.18, RN3.7, U5.9
/A16M: JP2.2, JP2.3, U1.39, U8.10
/A16M_C: JP2.1, U5.11
/A17C: J1.19, RN3.8, U5.8
/A17M: JP3.2, JP3.3, U1.40, U8.1
/A17M_C: JP3.1, U5.12
/A18C: JP6.3, RN3.9, U5.7
/A18M: JP4.2, JP4.3, U1.41, U8.4
/A18M_C: JP4.1, U5.13
/BANK2: RN5.5, SW3.3, TP1.1, U8.12
/BANK3: RN5.4, SW3.4, TP1.3, U8.8
/BANK4: RN5.3, SW3.5, TP1.5, U8.9, U8.11
/BANKB: RN5.9, SW2.3, TP1.6, U8.2
/BANKC: RN5.8, SW2.4, TP1.4, U8.6
/BANKD: RN5.7, SW2.5, TP1.2, U8.3, U8.5
/CEC: J1.22, R2.1
/D0C: J1.24, RN4.7, U6.10
/D0M: U1.9, U6.14
/D1C: J1.25, RN4.8, U6.9
/D1M: U1.10, U6.15
/D2C: J1.26, RN4.9, U6.8
/D2M: U1.13, U6.16
/D3C: J1.27, RN4.10, U6.7
/D3M: U1.14, U6.17
/D4C: J1.28, RN4.2, U6.6
/D4M: U1.31, U6.18
/D5C: J1.29, RN4.3, U6.5
/D5M: U1.32, U6.19
/D6C: J1.30, RN4.4, U6.4
/D6M: U1.35, U6.20
/D7C: J1.31, RN4.5, U6.3
/D7M: U1.36, U6.21
/WR_EN: J1.20, JP6.1, JP6.2, SW1.1
/~CEC: U5.4, U7.4
/~CEM: U1.8, U5.16
/~OEC: J1.23, R3.1
/~OEM: U1.37, U5.17
/~WEC: J1.21, R1.1
/~WEM: JP5.2, JP5.3, U1.15, U5.15
GND: C1.2, C2.2, C3.2, C4.2, C5.2, C6.2, C7.2, C8.2, C9.2, C10.2, C11.2, J1.32, RN5.1, SW1.3, U1.12, U1.34, U2.2, U3.1, U3.10, U3.19, U4.1, U4.10, U4.19, U5.1, U5.10, U5.19, U6.11, U6.12, U6.13, U6.22, U7.2, U7.3, U7.7, U7.8, U7.9, U7.11, U7.12, U8.7
unnamed: C12.1, R1.2, RN3.2, U5.5
unnamed: C13.1, R2.2, RN3.3, U7.5, U7.6
unnamed: C14.1, R3.2, RN3.4, U5.3, U6.2
unnamed: J1.33, R4.1
unnamed: RN3.5, U5.2
unnamed: RN3.10, U5.6

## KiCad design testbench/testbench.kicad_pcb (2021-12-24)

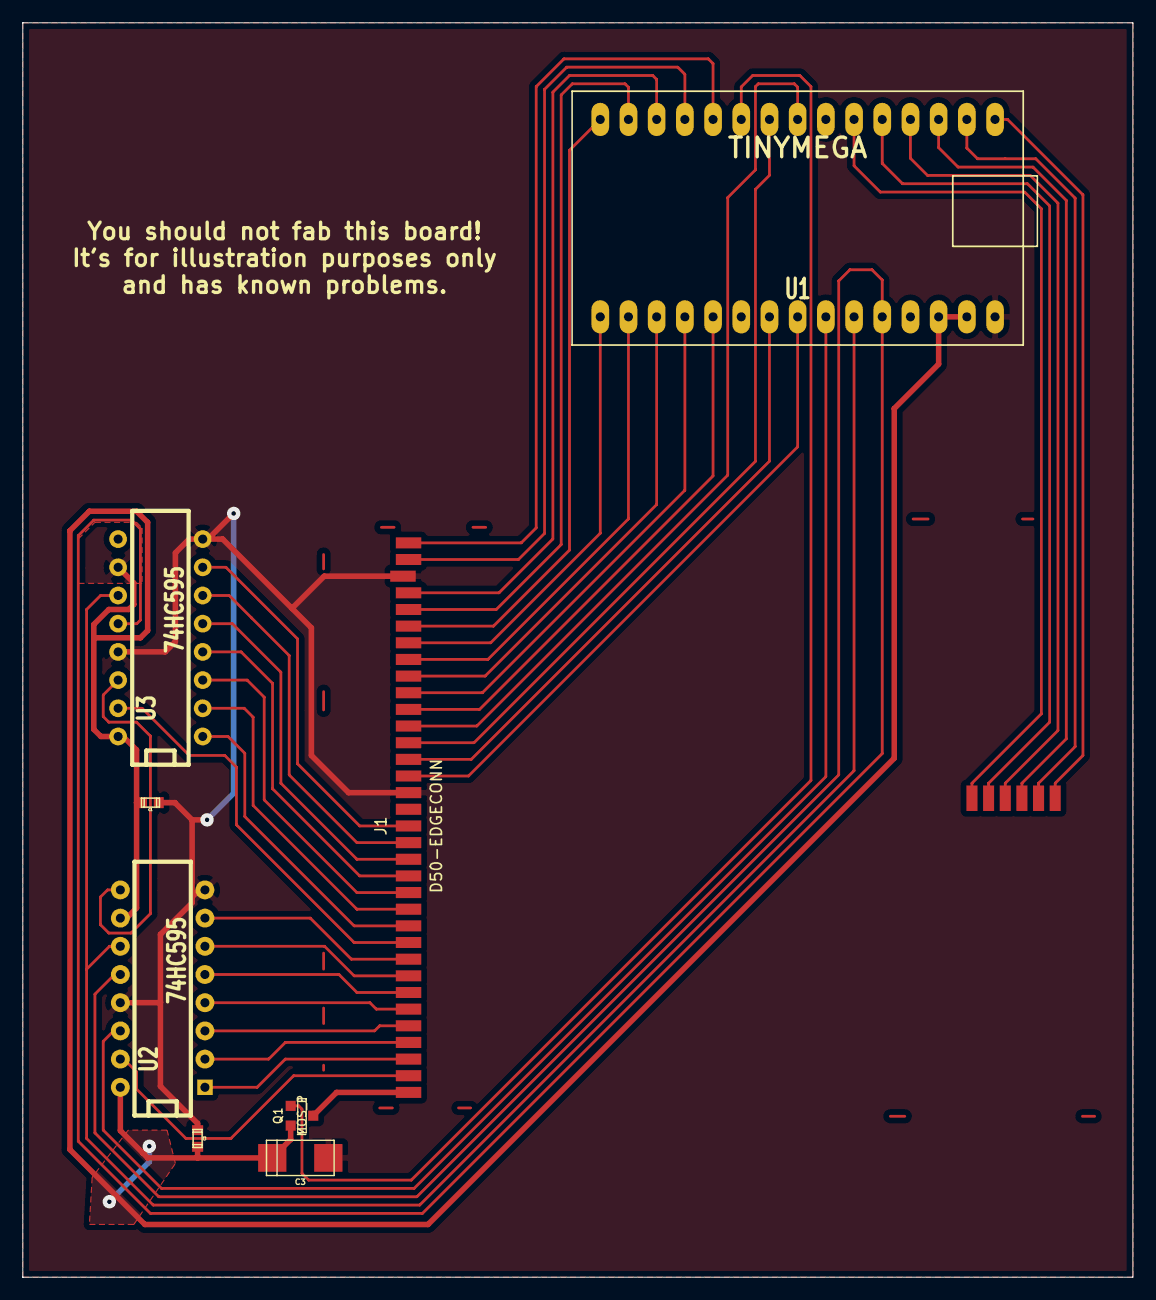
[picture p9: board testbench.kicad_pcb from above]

Board: 2 copper layers, 100.0 x 113.0 mm, 9 parts (0 on the bottom side), 45 nets.

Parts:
C1, C2: 100n; c_0603
C3: 4u7; c_tant_C
J1: D50-EDGECONN; d50conn_test
J2: CONN_6; 6P_TESTPT
Q1: MOS_P; SOT23GDS
U1: TINYMEGA; TinyMega
U2, U3: 74HC595; DIP-16__300

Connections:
+5V: C1.1, C2.1, C3.1, Q1.S, U1.2, U1.3, U2.10, U2.16, U3.10, U3.16
/A16: J1.18, U1.4
GND: C1.2, C2.2, C3.2, J1.19, J1.32, U1.1, U2.8, U2.13, U3.8, U3.13
unnamed: J1.1, Q1.D
unnamed: J1.2, U2.15
unnamed: J1.3, U2.1
unnamed: J1.4, U2.2
unnamed: J1.5, U2.3
unnamed: J1.6, U2.4
unnamed: J1.7, U2.5
unnamed: J1.8, U2.6
unnamed: J1.9, U2.7
unnamed: J1.10, U3.15
unnamed: J1.11, U3.1
unnamed: J1.12, U3.2
unnamed: J1.13, U3.3
unnamed: J1.14, U3.4
unnamed: J1.15, U3.5
unnamed: J1.16, U3.6
unnamed: J1.17, U3.7
unnamed: J1.20, U1.8
unnamed: J1.21, U1.9
unnamed: J1.22, U1.22
unnamed: J1.23, U1.23
unnamed: J1.24, U1.11
unnamed: J1.25, U1.12
unnamed: J1.26, U1.13
unnamed: J1.27, U1.14
unnamed: J1.28, U1.15
unnamed: J1.29, U1.16
unnamed: J1.30, U1.17
unnamed: J1.31, U1.18
unnamed: J1.33, U1.19
unnamed: J1.34, U1.20
unnamed: J2.1, U1.25
unnamed: J2.2, U1.26
unnamed: J2.3, U1.27
unnamed: J2.4, U1.28
unnamed: J2.5, U1.29
unnamed: J2.6, U1.30
unnamed: Q1.G, U1.21
unnamed: U1.5, U2.12, U3.12
unnamed: U1.6, U2.11, U3.11
unnamed: U1.7, U2.14
unnamed: U2.9, U3.14

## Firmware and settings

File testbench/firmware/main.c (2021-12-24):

/*
             LUFA Library
     Copyright (C) Dean Camera, 2017.

  dean [at] fourwalledcubicle [dot] com
           www.lufa-lib.org
*/

/*
  Copyright 2017  Dean Camera (dean [at] fourwalledcubicle [dot] com)

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
  The author disclaims all warranties with regard to this
  software, including all implied warranties of merchantability
  and fitness.  In no event shall the author be liable for any
  special, indirect or consequential damages or any damages
  whatsoever resulting from loss of use, data or profits, whether
  in an action of contract, negligence or other tortious action,
  arising out of or in connection with the use or performance of
  this software.
*/

/** \file
 *
 *  Main source file for the VirtualSerial demo. This file contains the main tasks of
 *  the demo and is responsible for the initial application hardware configuration.
 */

#include "main.h"
#include "test.h"

/** LUFA CDC Class driver interface configuration and state information. This structure is
 *  passed to all CDC Class driver functions, so that multiple instances of the same class
 *  within a device can be differentiated from one another.
 */
USB_ClassInfo_CDC_Device_t VirtualSerial_CDC_Interface =
	{
		.Config =
			{
				.ControlInterfaceNumber   = INTERFACE_ID_CDC_CCI,
				.DataINEndpoint           =
					{
						.Address          = CDC_TX_EPADDR,
						.Size             = CDC_TXRX_EPSIZE,
						.Banks            = 1,
					},
				.DataOUTEndpoint =
					{
						.Address          = CDC_RX_EPADDR,
						.Size             = CDC_TXRX_EPSIZE,
						.Banks            = 1,
					},
				.NotificationEndpoint =
					{
						.Address          = CDC_NOTIFICATION_EPADDR,
						.Size             = CDC_NOTIFICATION_EPSIZE,
						.Banks            = 1,
					},
			},
	};

/** Standard file stream for the CDC interface when set up, so that the virtual CDC COM port can be
 *  used like any regular character stream in the C APIs.
 */
static FILE USBSerialStream;


/** Main program entry point. This routine contains the overall program flow, including initial
 *  setup of all components and the main program loop.
 */
int main(void)
{
	SetupHardware();

	/* Create a regular character stream for the interface so that it can be used with the stdio.h functions */
	CDC_Device_CreateStream(&VirtualSerial_CDC_Interface, &USBSerialStream);
	stdout = &USBSerialStream;

	LEDs_SetAllLEDs(LEDMASK_USB_NOTREADY);
	GlobalInterruptEnable();

	for (;;)
	{
		test();
	}
}

/** Configures the board hardware and chip peripherals for the demo's functionality. */
void SetupHardware(void)
{
#if (ARCH == ARCH_AVR8)
	/* Disable watchdog if enabled by bootloader/fuses */
	MCUSR &= ~(1 << WDRF);
	wdt_disable();

	/* Disable clock division */
	clock_prescale_set(clock_div_1);
#elif (ARCH == ARCH_XMEGA)
	/* Start the PLL to multiply the 2MHz RC oscillator to 32MHz and switch the CPU core to run from it */
	XMEGACLK_StartPLL(CLOCK_SRC_INT_RC2MHZ, 2000000, F_CPU);
	XMEGACLK_SetCPUClockSource(CLOCK_SRC_PLL);

	/* Start the 32MHz internal RC oscillator and start the DFLL to increase it to 48MHz using the USB SOF as a reference */
	XMEGACLK_StartInternalOscillator(CLOCK_SRC_INT_RC32MHZ);
	XMEGACLK_StartDFLL(CLOCK_SRC_INT_RC32MHZ, DFLL_REF_INT_USBSOF, F_USB);

	PMIC.CTRL = PMIC_LOLVLEN_bm | PMIC_MEDLVLEN_bm | PMIC_HILVLEN_bm;
#endif

	/* Hardware Initialization */
	test_init();
	USB_Init();
}

/** Checks for changes in the position of the board joystick, sending strings to the host upon each change. */
void CheckJoystickMovement(void)
{
	uint8_t     JoyStatus_LCL = Joystick_GetStatus();
	char*       ReportString  = NULL;
	static bool ActionSent    = false;

	if (JoyStatus_LCL & JOY_UP)
	  ReportString = "Joystick Up\r\n";
	else if (JoyStatus_LCL & JOY_DOWN)
	  ReportString = "Joystick Down\r\n";
	else if (JoyStatus_LCL & JOY_LEFT)
	  ReportString = "Joystick Left\r\n";
	else if (JoyStatus_LCL & JOY_RIGHT)
	  ReportString = "Joystick Right\r\n";
	else if (JoyStatus_LCL & JOY_PRESS)
	  ReportString = "Joystick Pressed\r\n";
	else
	  ActionSent = false;

	if ((ReportString != NULL) && (ActionSent == false))
	{
		ActionSent = true;

		/* Write the string to the virtual COM port via the created character stream */
		fputs(ReportString, &USBSerialStream);

		/* Alternatively, without the stream: */
		// CDC_Device_SendString(&VirtualSerial_CDC_Interface, ReportString);
	}
}

/** Event handler for the library USB Connection event. */
void EVENT_USB_Device_Connect(void)
{
	LEDs_SetAllLEDs(LEDMASK_USB_ENUMERATING);
}

/** Event handler for the library USB Disconnection event. */
void EVENT_USB_Device_Disconnect(void)
{
	LEDs_SetAllLEDs(LEDMASK_USB_NOTREADY);
}

/** Event handler for the library USB Configuration Changed event. */
void EVENT_USB_Device_ConfigurationChanged(void)
{
	bool ConfigSuccess = true;

	ConfigSuccess &= CDC_Device_ConfigureEndpoints(&VirtualSerial_CDC_Interface);

	LEDs_SetAllLEDs(ConfigSuccess ? LEDMASK_USB_READY : LEDMASK_USB_ERROR);
}

/** Event handler for the library USB Control Request reception event. */
void EVENT_USB_Device_ControlRequest(void)
{
	CDC_Device_ProcessControlRequest(&VirtualSerial_CDC_Interface);
}

/** CDC class driver callback function the processing of changes to the virtual
 *  control lines sent from the host..
 *
 *  \param[in] CDCInterfaceInfo  Pointer to the CDC class interface configuration structure being referenced
 */
void EVENT_CDC_Device_ControLineStateChanged(USB_ClassInfo_CDC_Device_t *const CDCInterfaceInfo)
{
	/* You can get changes to the virtual CDC lines in this callback; a common
	   use-case is to use the Data Terminal Ready (DTR) flag to enable and
	   disable CDC communications in your application when set to avoid the
	   application blocking while waiting for a host to become ready and read
	   in the pending data from the USB endpoints.
	*/
	bool HostReady = (CDCInterfaceInfo->State.ControlLineStates.HostToDevice & CDC_CONTROL_LINE_OUT_DTR) != 0;
}

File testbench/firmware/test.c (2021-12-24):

/*
This is free and unencumbered software released into the public domain.

Anyone is free to copy, modify, publish, use, compile, sell, or
distribute this software, either in source code form or as a compiled
binary, for any purpose, commercial or non-commercial, and by any
means.

In jurisdictions that recognize copyright laws, the author or authors
of this software dedicate any and all copyright interest in the
software to the public domain. We make this dedication for the benefit
of the public at large and to the detriment of our heirs and
successors. We intend this dedication to be an overt act of
relinquishment in perpetuity of all present and future rights to this
software under copyright law.

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
For more information, please refer to <https://unlicense.org>
*/

#include <stdio.h>
#include <inttypes.h>

#include <avr/io.h>
#include <avr/pgmspace.h>
#include <avr/cpufunc.h>
#include <util/delay.h>

#include "main.h"
#include "test.h"

extern USB_ClassInfo_CDC_Device_t VirtualSerial_CDC_Interface;

/* Resource usage:
 *  SPI  - used to scan out the next address
 *  T/C1 - For timing
 *  ADC  - For verifying supply voltages
 */

// Access bits like variables
struct bits {
  uint8_t b0:1, b1:1, b2:1, b3:1, b4:1, b5:1, b6:1, b7:1;
} __attribute__((__packed__));
#define SBIT_(port,pin) ((*(volatile struct bits*)&port).b##pin)
#define	SBIT(x,y)       SBIT_(x,y)

/* === HW mapping === */

#define LATCH        SBIT(PORTB, 0)
//      SCLK              PORTB, 1
//      MOSI              PORTB, 2
#define WR_EN        SBIT( PINB, 3)
#define VBAT         0x23  // B4 / ADC11
#define V5V          0x24  // B5 / ADC12
#define POWER_ON_B   SBIT(PORTB, 6)
#define WE_B         SBIT(PORTB, 7)
#define CE           SBIT(PORTC, 6)
#define OE_B         SBIT(PORTC, 7)
#define WDATA        PORTD
#define RDATA        PIND
#define DDATA        DDRD
#define BUTTON_B     SBIT( PINE, 2)
#define LED_A16      SBIT(PORTE, 6) // The LED doubles as A16 if we operate in 1Mbit mode

#define BANKSW       PINF
#define BANK_2       (1 << 7)
#define BANK_3       (1 << 5)
#define BANK_4       (1 << 1)
#define BANK_B       (1 << 0)
#define BANK_C       (1 << 4)
#define BANK_D       (1 << 6)

static void test_reset(void);

void test_init(void)
{
	/* Disable JTAG to free PORTF */
	MCUCR = 1 << JTD;
	MCUCR = 1 << JTD;

	/* Set up port directions and states */
	PORTB = (1 << PB6) | (1 << PB7);
	DDRB = (1 << PB0) | (1 << PB1) | (1 << PB2) | (1 << PB6) | (1 << PB7);
	PORTC = 1 << PC7;
	DDRC = (1 << PC6) | (1 << PC7);
	PORTD = 0;
	DDRD = 0;
	PORTE = (1 << PE2);
	DDRE = (1 << PE6);
	PORTF = 0;
	DDRF = 0;

	/* Set up T/C1 to count at 16us period, no interrupts */
	TCCR1A = 0;
	TIMSK1 = 0;
	TCCR1B = 4 << CS10;

	/* Set up SPI: No interrupt, Master, MSB first, idle clock low, 8 MHz */
	SPCR = (1 << SPE) | (0 << DORD) | (1 << MSTR) | (0 << CPOL) | (0 << SPR0);
	//SPSR = (1 << SPI2X);

	/* Disconnect digital inputs from ADC ports */
	DIDR2 = (1 << ADC11D) | (1 << ADC12D);

	test_reset();
}

static int16_t usb(void)
{
	CDC_Device_USBTask(&VirtualSerial_CDC_Interface);
	USB_USBTask();

	return CDC_Device_ReceiveByte(&VirtualSerial_CDC_Interface);
}

#define LOG(msg, args...) do { printf_P(PSTR(msg), ##args); usb(); } while (1==0)
#define FAIL(msg, args...) do { LOG("FAIL: " msg "\n", ##args); goto out; } while (1==0)

static uint8_t button_pressed(void)
{
	static uint8_t last_button_state = 0;
	uint8_t b = !BUTTON_B;
	uint8_t button_press = ((b != last_button_state) && b);
	last_button_state = b;
	return button_press;
}

static inline void timer_set(uint32_t us)
{
	GTCCR = 1 << PSRSYNC;        // Reset prescaler
	TCNT1 = (65536 - (us / 16)); // Set counter start value
	TIFR1 = 1 << TOV1;           // Clear overflow flag
}

#define TIMER_EXPIRED (TIFR1 & (1 << TOV1))

static void wait(uint32_t us)
{
	timer_set(us);
	while (!TIMER_EXPIRED)
		usb();
}

static void set_address(uint16_t address)
{
	SPDR = address >> 8;
	while (!(SPSR & (1 << SPIF)));
	SPDR = address & 0xFF;
	while (!(SPSR & (1 << SPIF)));
	LATCH = 1;
	LATCH = 0;
}

static void write_mode(void)
{
	OE_B = 1;
	WE_B = 1;
	DDATA = 0xFF;
	CE = 1;
}

static void read_mode(void)
{
	WDATA = 0;
	DDATA = 0;
	OE_B = 0;
	WE_B = 1;
	CE = 1;
}

static void disable_mram(void)
{
	OE_B = 1;
	WE_B = 1;
	CE = 0;
	WDATA = 0;
	DDATA = 0;
}

static void write_byte(uint16_t address, uint8_t data)
{
	set_address(address);
	WDATA = data;
//	_delay_us(1);
	WE_B = 0;
//	_delay_us(1);
	WE_B = 1;
//	_delay_us(1);
}

static uint8_t read_byte(uint16_t address)
{
	set_address(address);
//	_delay_us(2);
	return RDATA;
}

static uint8_t read_adc(uint8_t channel)
{
	ADMUX = (1 << ADLAR) | (channel & 0x1F);
	ADCSRB = (((channel >> 5) & 1) << MUX5);
	/* 250 kHz, no int */
	ADCSRA = (1 << ADEN) | (1 << ADSC) | (1 << ADIF) | (6 << ADPS0);
	while (!(ADCSRA & (1 << ADIF)));
	return ADCH;
}

static uint8_t bank_sw_stable_value = 0, bank_sw_new_value = 0, bank_sw_stable_count = 0;

static void reset_bank_sw(void)
{
	bank_sw_stable_value = 0xFF;  // impossible value since not all bits of PINF have corresponding pins
}

static uint8_t get_bank_sw(void)
{
	wait(1000);

	uint8_t b = BANKSW;
	LOG("%02X\b\b", b);
	if (b != bank_sw_stable_value) {
		if (b == bank_sw_new_value) {
			if (bank_sw_stable_count)
				bank_sw_stable_count--;
			else
				bank_sw_stable_value = bank_sw_new_value;
		} else {
			bank_sw_new_value = b;
			bank_sw_stable_count = 20;
		}
		return 0;
	}

	return 1;
}

static uint8_t get_bank_1234(void)
{
	while (!get_bank_sw() && !button_pressed());

	switch (bank_sw_stable_value & (BANK_2 | BANK_3 | BANK_4)) {
	case 0: return 1;
	case BANK_2: return 2;
	case BANK_3: return 3;
	case BANK_4: return 4;
	default:
		LOG("Invalid bank value 0x%02x\n", bank_sw_stable_value);
		return 0;
	}
}

static uint8_t get_bank_ABCD(void)
{
	while (!get_bank_sw() && !button_pressed());

	switch (bank_sw_stable_value & (BANK_B | BANK_C | BANK_D)) {
	case 0: return 1;
	case BANK_B: return 2;
	case BANK_C: return 3;
	case BANK_D: return 4;
	default:
		LOG("Invalid bank value 0x%02x\n", bank_sw_stable_value);
		return 0;
	}
}

static uint8_t wait_bank(uint8_t level, uint8_t which)
{
	uint8_t bank;

	while (1) {
		if (button_pressed())
			return 0;
		bank = level ? get_bank_ABCD() : get_bank_1234();
		if (bank == 0)
			return 0;
		if (bank == which)
			return 1;
	}
}

static uint8_t wait_wr_en(uint8_t value)
{
	uint8_t b;

	while (1) {
		if (button_pressed())
			return 0;
		b = WR_EN;
		_delay_ms(1);
		if ((WR_EN == b) && (b == value))
			return 1;
	}
}

static void test_reset(void)
{
	reset_bank_sw();
	disable_mram();
	set_address(0);
	POWER_ON_B = 1;
}
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

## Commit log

2021-12-24 Initial open-source release
    [d50mram.bom.csv, d50mram.kicad_pcb, d50mram.sch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]
2022-02-23 Replacement resistor networks work fine!
    Thanks a lot to @MrMojoRisinGottaKeepOnRisin for reporting back!
2023-01-02 Update to KiCad 6, add Mouser part numbers
    Also add a note stating that MIC5245 is a valid replacement
    for the MIC5265.
    Thanks to @HSBallina for all the parts sleuthing!
    Closes #4.
    [d50mram.bom.csv, d50mram.kicad_pcb, d50mram.kicad_sch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]
